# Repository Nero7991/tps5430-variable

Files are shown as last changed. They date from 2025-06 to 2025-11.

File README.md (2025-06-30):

# TPS5430 Variable or VarTPS

This is a DC-DC Buck converter board based on the TPS5430 from TI with both fixed and variable voltage output options, called VarTPS. The board provides four fixed voltage outputs (1.8V, 3.3V, 5V, 12V) selectable via solder jumpers, plus a variable output mode ranging from 1.24V to 32.4V. Variable voltage control is implemented using two 10-turn potentiometers - a 10kΩ potentiometer for coarse adjustment and a 1kΩ potentiometer for fine adjustment, providing approximately 3mV resolution at low voltages. The design includes reverse polarity protection, overcurrent protection via polyfuse, and accepts input and output throught screw terminals.

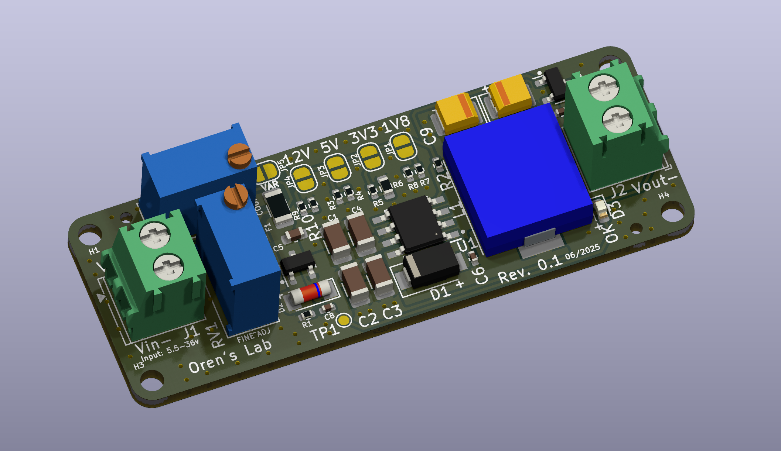
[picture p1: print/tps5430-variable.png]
Raytrace 3D rendered image of the VarTPS board VarTPS


## Features

* V<sub>in</sub> = 5.5V..36V
* V<sub>in<sub>min</sub></sub> = 1.15 * V<sub>out</sub> (see Datasheet Section 8.2.1.2.8.1)
* V<sub>in<sub>max</sub></sub> = 8.33 * (V<sub>out</sub> + 0.5) (see Datasheet Section 8.2.1.2.8.1)
* V<sub>out</sub> = 1.8V/3.3V/5V/12V (choose via solder bridge)
* Variable voltage out, adjusted using two 10 turn pot with course and fine adjustments. V<sub>out<sub>adjust</sub></sub> = 1.24V..32.4V (choosen via solder bridge)
* Reverse polarity protection with AO3401A p-MOSFET
* 3A (hold)/6A (trip) polyfuse input protection
* The board can be powered with a 2.1mm/5.5mm "standard" Arduino compatible barrel jack connector.
* Status LED

## Schematic

The design was modified in [KiCAD 9](https://www.kicad.org/) from Max Stabel's [TPS5430 on GitHub](https://github.com/M4a1x/TPS5430) and follows the [TPS5430 datasheet (Section 8.2.1)](https://www.ti.com/lit/ds/symlink/tps5430.pdf) reasonably close in the schmatic as well as the layout (Section 10.2).

Deviations are:

* 2x 100uF tantalum capacitors instead of 1x 220uF, since those are basic parts at JLCPCB
* As suggested a 10uF output bypass capacitor is added
* 4x 10uF input capacitors instead of only 1x
* Multiple output voltage options through increased Inductor (47uH instead of 15uH) and solder jumpers. All outputs should work with the full 3A

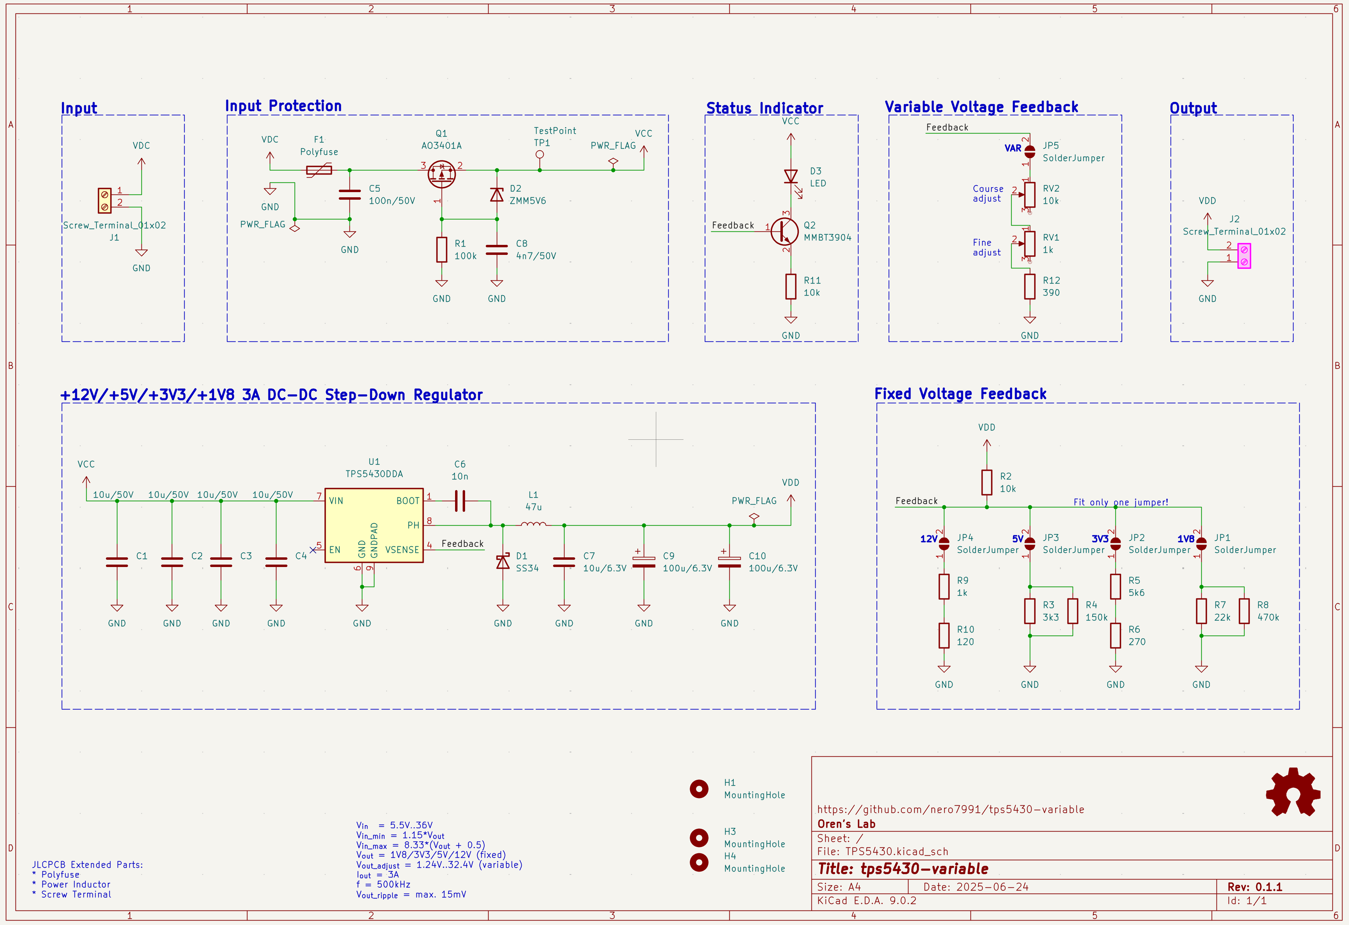
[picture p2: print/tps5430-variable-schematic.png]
Full schematic Schematic


## License

Licensed under CERN-OHL-S v2 or any later version. See `LICENSE` for more information.

## Contact

Oren Collaco - [https://orencollaco.com/](https://orencollaco.com) - orencollaco97@gmail.com

Project Link: [https://github.com/Nero7991/tps5430-variable](https://github.com/Nero7991/tps5430-variable)

## Acknowledgements

* [Max Stabel](https://max.stabel.family/), [TPS5430 on GitHub](https://github.com/M4a1x/TPS5430)

* [Philip Salamony](https://philsal.co.uk/) and his [BananaSchplit Project](https://github.com/pms67/BananaSchplit) and [Video](https://www.youtube.com/watch?v=qXWYXxDokv4)
* [ugurozkan52/TPS5430_Power_Module](https://github.com/ugurozkan52/TPS5430_Power_Module) which inspired me to add the output voltage jumpers

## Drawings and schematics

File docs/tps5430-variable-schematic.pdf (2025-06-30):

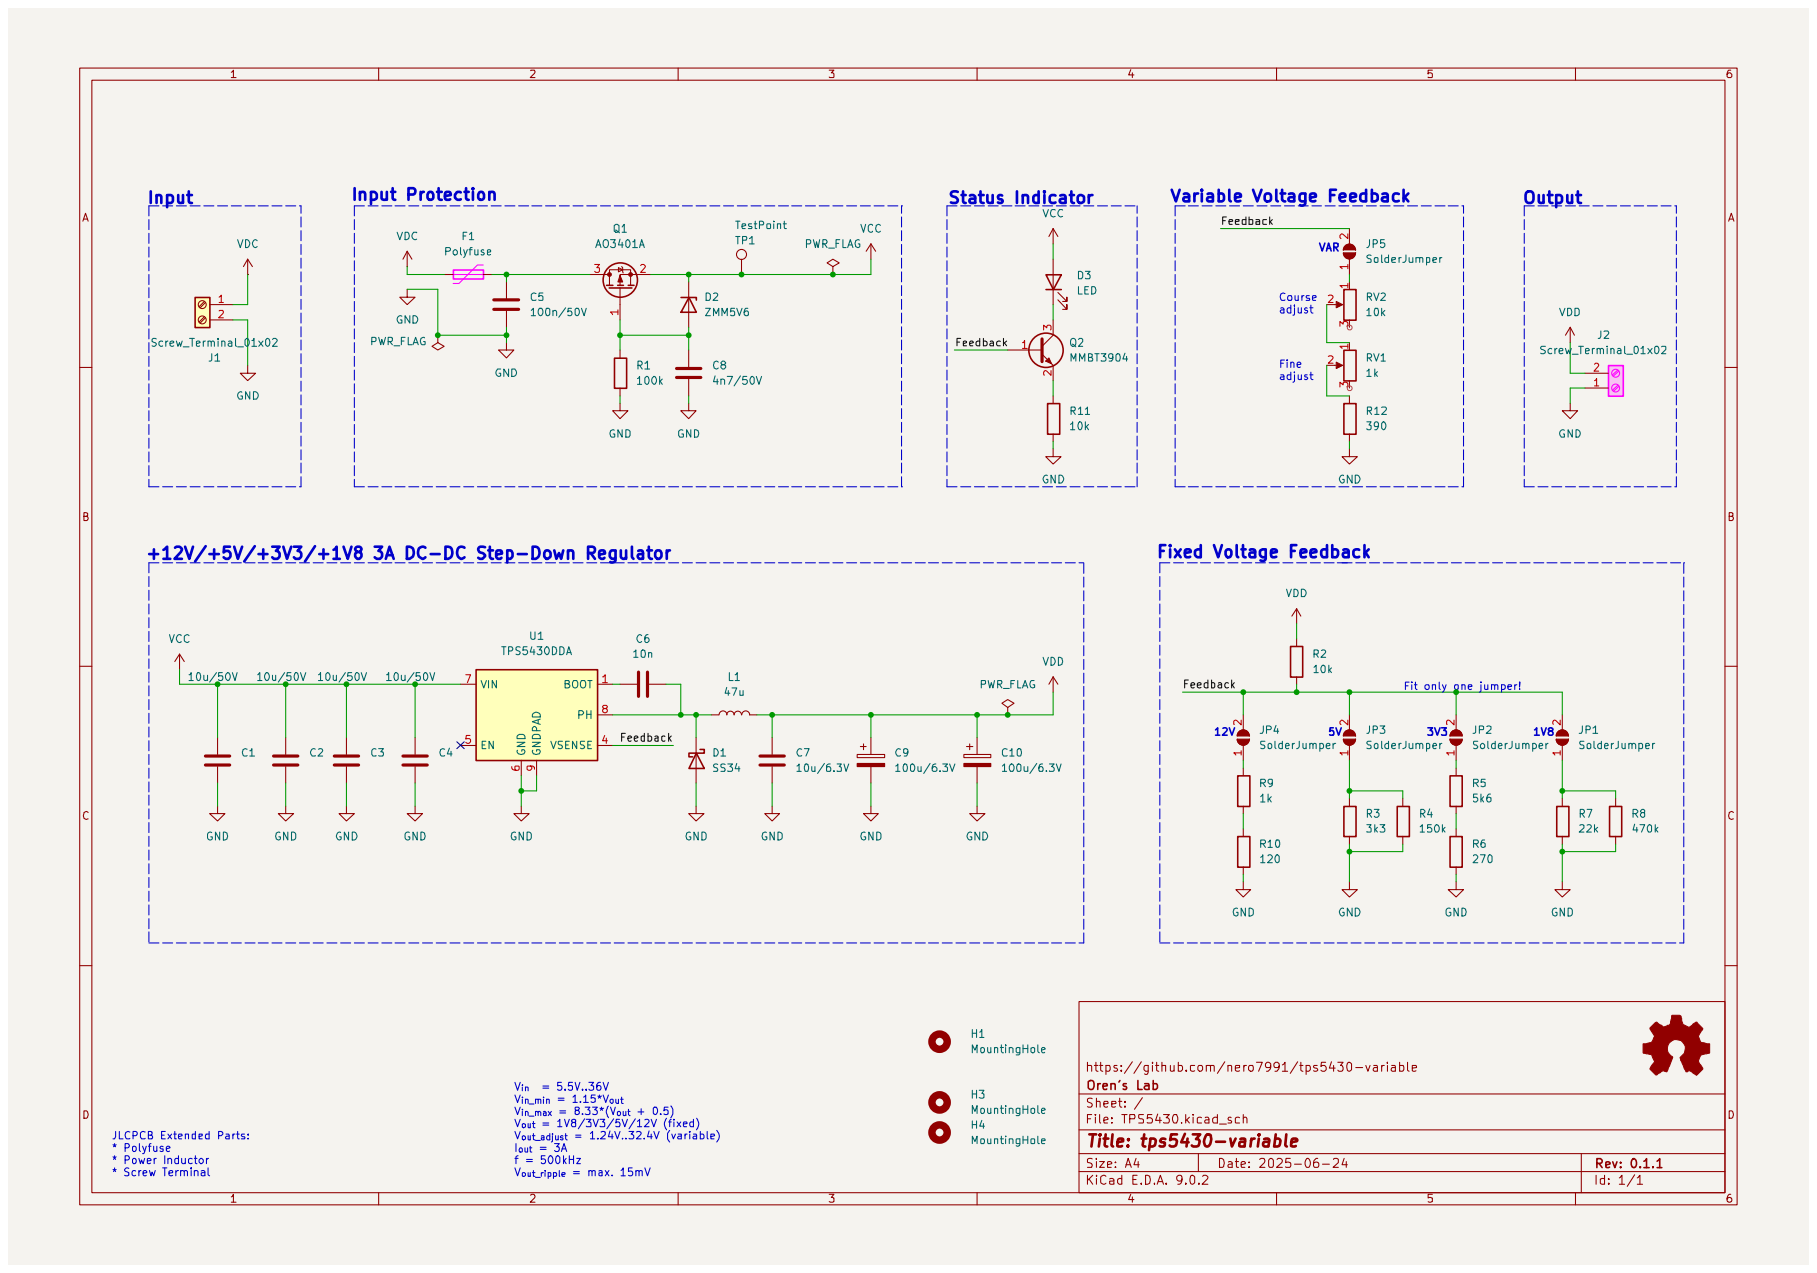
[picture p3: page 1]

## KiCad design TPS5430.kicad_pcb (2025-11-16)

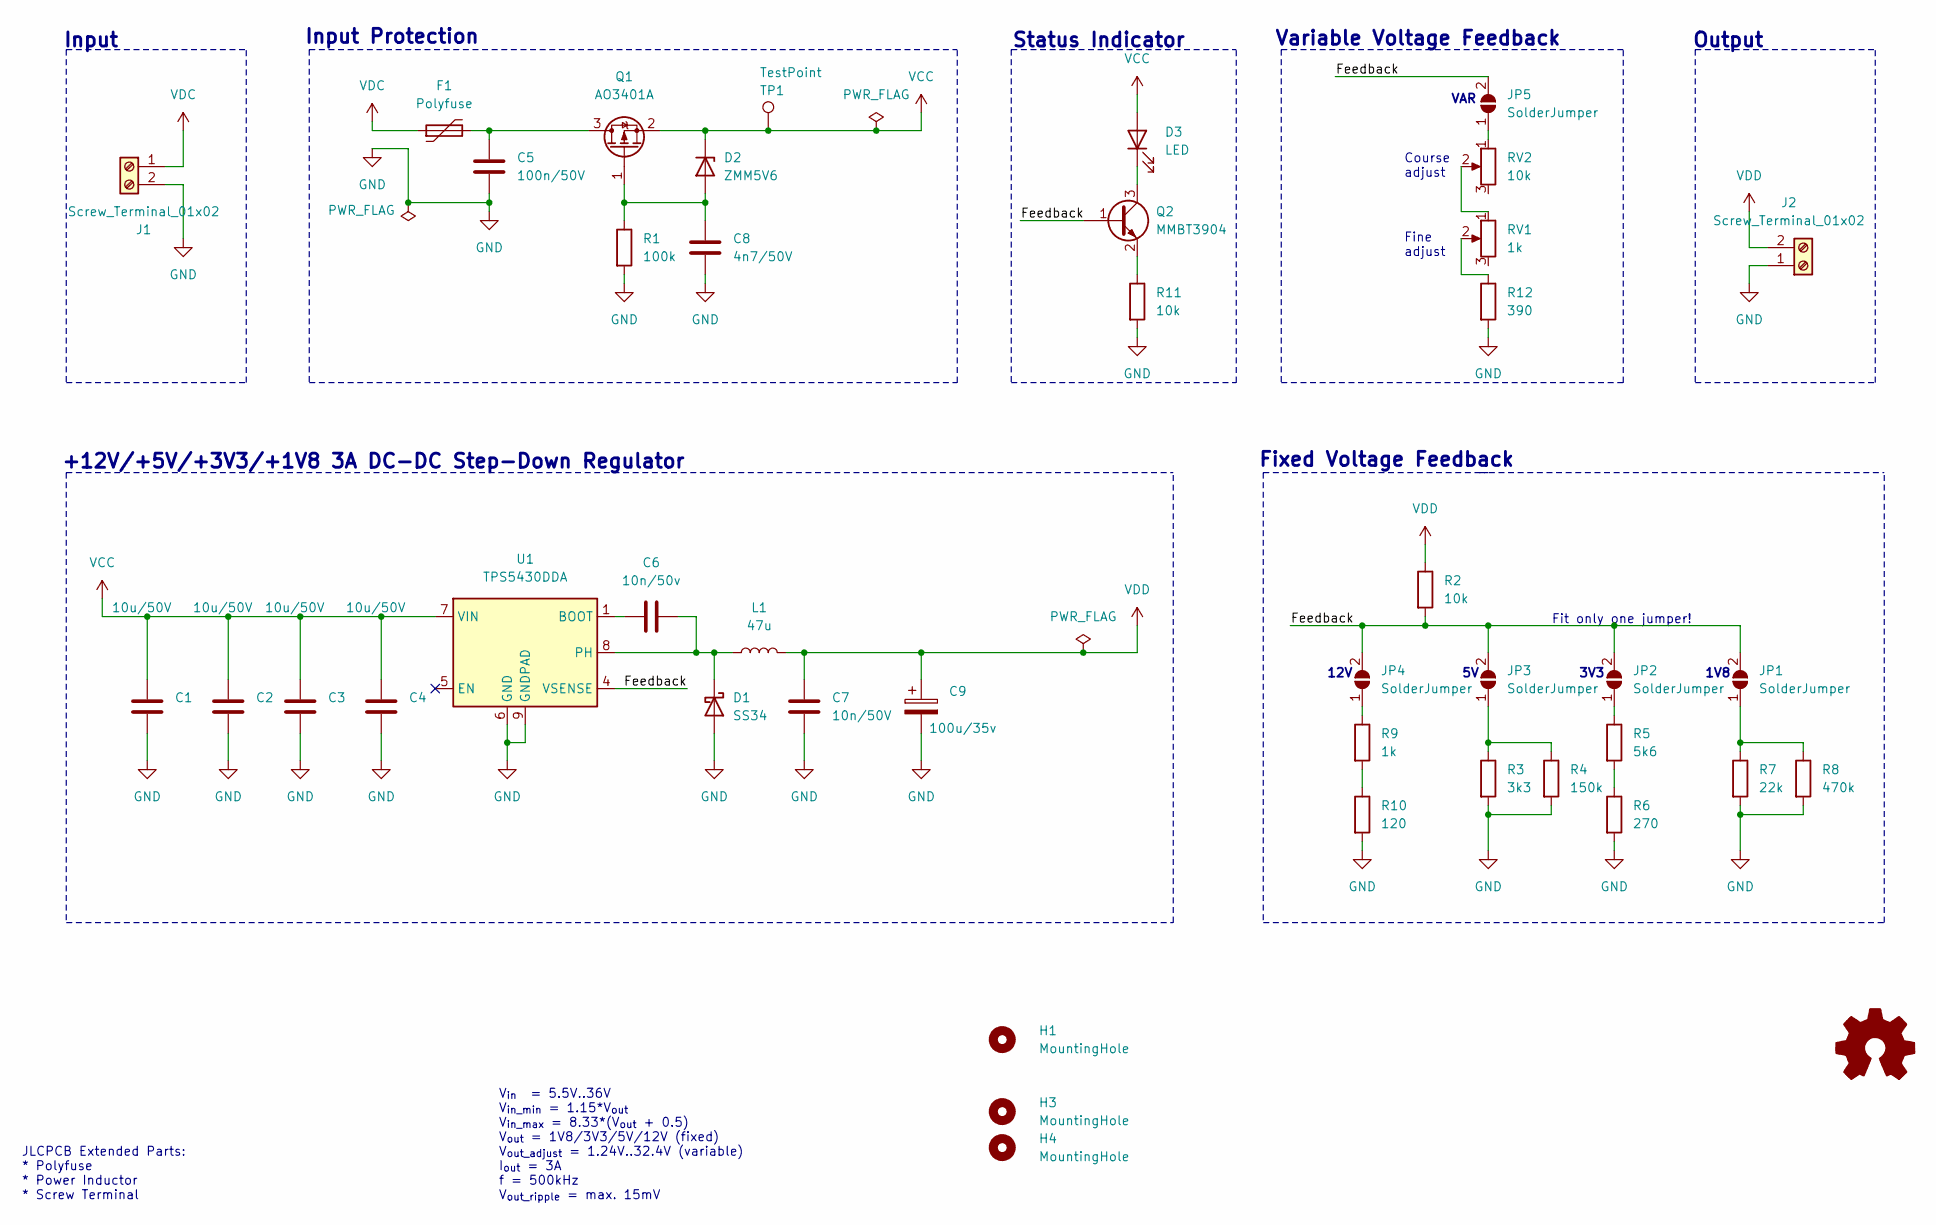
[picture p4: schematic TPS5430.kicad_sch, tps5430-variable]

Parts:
C1, C2, C3, C4: 10u/50V; C_1206_3216Metric; MPN CL31A106KBHNNNE; LCSC C13585
C5: 100n/50V; C_0603_1608Metric; MPN CC0603KRX7R9BB104; LCSC C14663
C6: 10n/50v; C_0402_1005Metric; MPN CL05B103KB5NNNC; LCSC C15195
C7: 10n/50V; C_0402_1005Metric; MPN CL05A106MQ5NUNC; LCSC C15525
C8: 4n7/50V; C_0402_1005Metric; MPN 0402B472K500NT; LCSC C1538
C9: 100u/35v; CP_EIA-7343-43_Kemet-X; MPN TAJB107K006RNJ; LCSC C16133
D1: SS34; D_SMA; MPN SS34; LCSC C8678
D2: ZMM5V6; D_MiniMELF; MPN ZMM5V6; LCSC C8062
D3: LED; LED_0603_1608Metric; MPN 19-217/GHC-YR1S2/3T; LCSC C72043
F1: Polyfuse; Fuse_1206_3216Metric; MPN 1206L300SLTHYR; LCSC C207041
H1, H3, H4: MountingHole; MountingHole_2.2mm_M2_ISO7380
J1, J2: Screw_Terminal_01x02; TerminalBlock_Phoenix_PT-1,5-2-3.5-H_1x02_P3.50mm_Horizontal; MPN XY302V-3.5-2P; LCSC C784940
JP1, JP2, JP3, JP4, JP5: SolderJumper; SolderJumper-2_P1.3mm_Open_RoundedPad1.0x1.5mm
L1: 47u; L_Sunlord_MWSA1004S_10x11.5x4mm; MPN MWSA1004S-470MT; LCSC C408491
LOGO1: Logo_Open_Hardware_Small; OSHW-Logo_11.4x12mm_Copper
Q1: AO3401A; SOT-23; MPN AO3401A; LCSC C15127
Q2: MMBT3904; SOT-23; MPN MMBT3904; LCSC C20526
R1: 100k; R_0402_1005Metric; MPN 0402WGF1003TCE; LCSC C25741
R2: 10k; R_0402_1005Metric; MPN 0402WGF1002TCE; LCSC C25744
R3: 3k3; R_0402_1005Metric; MPN 0402WGF3301TCE; LCSC C25890
R4: 150k; R_0402_1005Metric; MPN 0402WGF1503TCE; LCSC C25755
R5: 5k6; R_0402_1005Metric; MPN 0402WGF5601TCE; LCSC C25908
R6: 270; R_0603_1608Metric; MPN 0603WAF2700T5E; LCSC C22966
R7: 22k; R_0402_1005Metric; MPN 0402WGF2202TCE; LCSC C25768
R8: 470k; R_0402_1005Metric; MPN 0402WGF4703TCE; LCSC C25790
R9: 1k; R_0402_1005Metric; MPN 0402WGF1001TCE; LCSC C11702
R10: 120; R_0402_1005Metric; MPN 0402WGF1200TCE; LCSC C25079
R11: 10k; R_0603_1608Metric; MPN 0603WAF1002T5E; LCSC C25804
R12: 390; R_0603_1608Metric; MPN 0603WAF2700T5E; LCSC C22966
RV1: 1k; Potentiometer_Bourns_3296W_Vertical
RV2: 10k; Potentiometer_Bourns_3296W_Vertical
TP1: TestPoint; TestPoint_Pad_D1.0mm
U1: TPS5430DDA; TI_SO-PowerPAD-8_ThermalVias; MPN TPS5430DDAR; JLC LSOP-8_EP_3.9x4.9x1.27P

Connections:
/Feedback: JP1.2 (B), JP2.2 (B), JP3.2 (B), JP4.2 (B), JP5.2 (B), Q2.1 (B), R2.2, U1.4 (VSENSE)
GND: C1.2, C2.2, C3.2, C4.2, C5.2, C7.2, C8.2, C9.2, D1.2 (A), J1.2, J2.1, R1.2, R3.2, R4.2, R6.2, R7.2, R8.2, R10.2, R11.2, R12.2, U1.6 (GND), U1.9 (GNDPAD); also elsewhere on the board
unnamed: C6.2, D1.1 (K), L1.1, U1.8 (PH)
unnamed: C8.1, D2.2 (A), Q1.1 (G), R1.1
unnamed: D3.1 (K), Q2.3 (C)
unnamed: JP1.1 (A), R7.1, R8.1
unnamed: JP2.1 (A), R5.1
unnamed: JP3.1 (A), R3.1, R4.1
unnamed: JP4.1 (A), R9.1
unnamed: JP5.1 (A), RV2.1
unnamed: C5.1, F1.2, Q1.3 (D)
unnamed: Q2.2 (E), R11.1
unnamed: R5.2, R6.1
unnamed: R9.2, R10.1
unnamed: R12.1, RV1.2
unnamed: RV1.1, RV2.2
unnamed: C6.1, U1.1 (BOOT)
VCC: C1.1, C2.1, C3.1, C4.1, D2.1 (K), D3.2 (A), Q1.2 (S), TP1.1, U1.7 (VIN)
VDC: F1.1, J1.1
VDD: C7.1, C9.1, J2.2, L1.2, R2.1; also elsewhere on the board

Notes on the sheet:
Fit only one jumper!
Output
1V8
Input
Course adjust
Status Indicator
JLCPCB Extended Parts: * Polyfuse * Power Inductor * Screw Terminal
Fixed Voltage Feedback
3V3
12V
VAR
Input Protection
+12V/+5V/+3V3/+1V8 3A DC-DC Step-Down Regulator
V_{in} = 5.5V..36V V_{in_min} = 1.15*V_{out} V_{in_max} = 8.33*(V_{out} + 0.5) V_{out} = 1V8/3V3/5V/12V (fixed) V_{out_adjust} = 1.24V..32.4V (variable) I_{out} = 3A f = 500kHz V_{out_ripple} = max. 15mV
Variable Voltage Feedback
Fine adjust

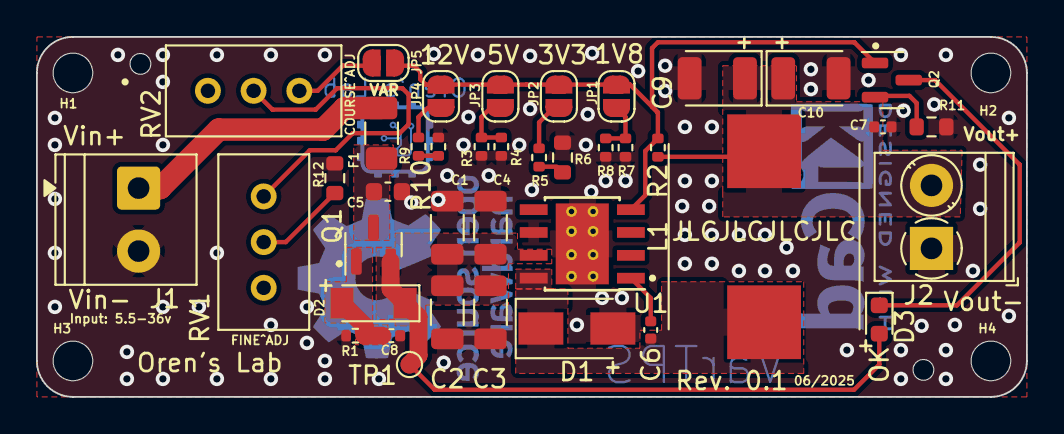
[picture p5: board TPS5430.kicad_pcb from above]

Board: 2 copper layers, 55.0 x 20.0 mm, 46 parts (1 on the bottom side), 20 nets.

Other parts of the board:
C10: 100u/6.3V; CP_EIA-3528-21_Kemet-B
H2: MountingHole; MountingHole_2.2mm_M2_ISO7380
Logo: LOGO; Orens_Lab_Logo_5x5mm.kicad_sym

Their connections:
GND: C10.2; also elsewhere on the board
VDD: C10.1; also elsewhere on the board

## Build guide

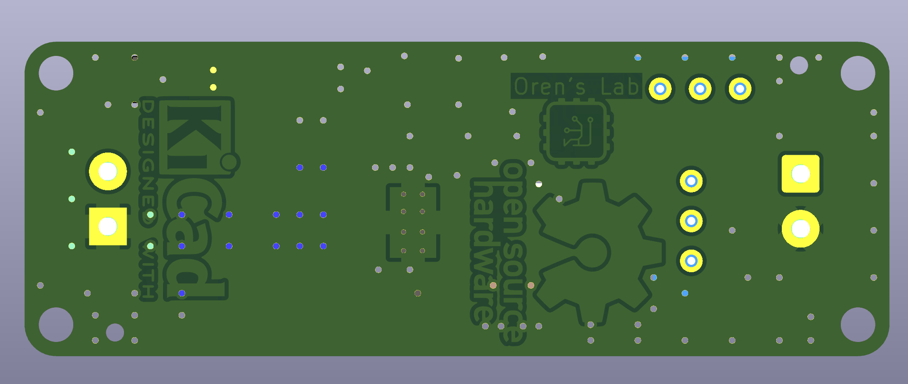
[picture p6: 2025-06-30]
print/tps5430-variable-bottom.png

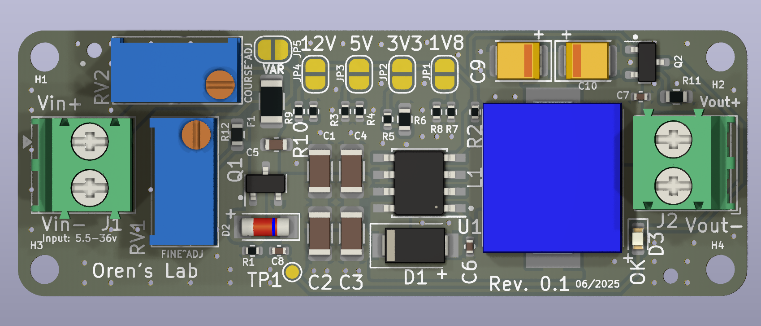
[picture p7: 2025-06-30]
print/tps5430-variable-top.png

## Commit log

2025-06-27 Initial addition of variable feedback block
    [TPS5430.kicad_sch]
2025-06-28 Finished variable feedback block
    [TPS5430.kicad_pcb, TPS5430.kicad_sch]
2025-06-30 Completed placement and routing; Updated REAMME and docs
    [TPS5430.kicad_pcb, TPS5430.kicad_sch]
2025-11-16 printed PCB updates
    [TPS5430.kicad_pcb, TPS5430.kicad_sch]
